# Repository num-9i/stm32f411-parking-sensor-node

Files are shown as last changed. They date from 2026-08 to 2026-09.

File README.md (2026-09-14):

# STM32F411RE Parking Sensor Node

STM32F411RE 기반으로 초음파 거리 측정, 주차 상태 판정, RGB LED 표시, Modbus RTU/RS485 통신을 구현한 주차 센서 노드 프로젝트입니다.

HC-SR04의 Echo pulse를 Timer Input Capture로 비동기 측정하고, 측정 결과에 hysteresis와 entry/exit delay를 적용해 `FREE / OCCUPIED / ERROR` 상태를 판정합니다.

센서 상태와 설정값은 Modbus Holding Register에 매핑했으며, `0x03 Read Holding Registers`와 `0x06 Write Single Register`를 통해 외부 Modbus Master에서 조회 및 변경할 수 있도록 구현했습니다.

현재 브레드보드 환경에서 펌웨어와 RS485 통신 검증을 완료했으며, NUCLEO-F411RE용 Carrier PCB도 Gerber/Drill 파일 생성 단계까지 완료했습니다. 실제 PCB 제작과 Bring-up은 다음 단계로 진행할 예정입니다.

## Project Status

- [x] Pin Map 정의
- [x] HC-SR04 거리 측정
- [x] TIM2 Input Capture / Interrupt 처리
- [x] 거리 측정 Timeout / Error Counter
- [x] FREE / OCCUPIED / ERROR 상태 판정
- [x] Hysteresis / Entry Delay / Exit Delay
- [x] RGB LED 상태 표시
- [x] Modbus RTU Function `0x03`
- [x] Modbus RTU Function `0x06`
- [x] Runtime Configuration
- [x] Modbus Exception Response
- [x] RS485 실통신 검증
- [x] Carrier PCB Schematic
- [x] Carrier PCB Layout / Routing
- [x] Carrier PCB ERC / DRC Verification
- [x] Gerber / Drill File Generation & Inspection
- [x] MAX3485용 PB5 DE/RE 제어 펌웨어 반영
- [ ] UART CLI
- [ ] PCB Fabrication
- [ ] PCB Bring-up / Hardware Verification

## System Overview

전체 데이터 흐름은 다음과 같습니다.

```text
HC-SR04
   │
   │ Echo Pulse
   ↓
TIM2 Input Capture
   │
   ↓
Distance Measurement
   │
   ↓
Parking State Logic
FREE / OCCUPIED / ERROR
   │
   ├──────────────→ RGB LED
   │
   ↓
Modbus Register Layer
   │
   ↓
Modbus RTU
   │
   ↓
USART1 / RS485
   │
   ↓
External Modbus Master
```

HC-SR04의 Echo pulse는 `TIM2_CH1 Input Capture`로 측정합니다.

측정된 거리 값은 주차 상태 판정 로직으로 전달되며, hysteresis와 entry/exit delay를 적용해 순간적인 거리 변화로 상태가 불필요하게 전환되는 것을 줄였습니다.

판정 결과와 센서 상태, 오류 카운터, 설정값은 Modbus Holding Register에 매핑해 외부 Master에서 확인할 수 있도록 구성했습니다.

## Hardware

### MCU / Development Board

- MCU: STM32F411RET6
- Board: NUCLEO-F411RE
- System Clock: 84 MHz

### Sensor / Indicator

- Distance Sensor: HC-SR04
- Status Indicator: Common Cathode RGB LED
- HC-SR04 Echo Interface: 1 kΩ / 2 kΩ Voltage Divider

### Communication

- Modbus UART: USART1
- Debug UART: USART2 / ST-LINK VCP
- Protocol: Modbus RTU
- Prototype RS485: Auto-direction TTL-to-RS485 Module
- Carrier PCB RS485: MAX3485
- PC Interface: USB-to-RS485 Adapter

상세 핀 구성은 아래 문서를 참고합니다.

- [Pin Map](docs/pin_map.md)

## HC-SR04 Distance Measurement

HC-SR04의 Trigger 신호를 출력한 뒤 Echo pulse의 High 구간을 측정해 거리를 계산합니다.

Echo 입력은 `PA0 / TIM2_CH1`에 연결하고, Timer를 1 MHz로 설정해 1 us 단위로 pulse width를 측정합니다.

```text
IDLE
  ↓
Trigger Pulse
  ↓
WAIT_RISING
  ↓
Rising Edge Capture
  ↓
WAIT_FALLING
  ↓
Falling Edge Capture
  ↓
Pulse Width Calculation
  ↓
DATA_READY
```

거리 계산에는 다음 관계를 사용합니다.

```text
Distance_mm = PulseWidth_us × 343 / 2000
```

센서 측정 범위는 약 `20 ~ 4000 mm`로 제한하며, 범위를 벗어난 pulse는 Invalid Pulse로 처리합니다.

정상적인 Echo 신호가 들어오지 않을 경우 무한 대기하지 않도록 Timeout을 적용했습니다.

구분하는 오류 항목은 다음과 같습니다.

- Rising Edge Timeout
- Falling Edge Timeout
- Invalid Pulse

각 오류는 별도의 Counter로 기록해 Modbus를 통해 확인할 수 있습니다.

## Parking State Logic

주차 상태는 다음 세 가지로 구분합니다.

| Value | State | Description |
|---:|---|---|
| `0` | FREE | 주차 공간이 비어 있는 상태 |
| `1` | OCCUPIED | 차량이 감지된 상태 |
| `2` | ERROR | 거리 측정이 일정 시간 이상 유효하지 않은 상태 |

기본 설정값은 다음과 같습니다.

```text
Occupied Threshold = 500 mm
Hysteresis         = 50 mm
Entry Delay        = 500 ms
Exit Delay         = 1000 ms
```

FREE 상태에서 거리가 `Occupied Threshold` 이하로 Entry Delay 동안 유지되면 OCCUPIED로 전환됩니다.

OCCUPIED 상태에서는 다음 기준을 사용합니다.

```text
Free Threshold =
    Occupied Threshold + Hysteresis
```

기본값 기준으로:

```text
Occupied Threshold = 500 mm
Free Threshold     = 550 mm
```

이므로 `500 mm < distance <= 550 mm` 구간에서는 현재 상태를 유지합니다.

따라서 임계값 부근에서 측정값이 흔들려도 상태가 즉시 반복 전환되지 않습니다.

거리 측정이 일정 시간 이상 유효하지 않을 경우 ERROR 상태로 전환합니다.

## RGB LED

주차 상태는 RGB LED로 표시합니다.

| Parking State | LED |
|---|---|
| FREE | Green |
| OCCUPIED | Red |
| ERROR | Blue |

GPIO 구성:

```text
PB12 → Red
PB13 → Green
PB14 → Blue
```

RGB LED는 Active High 방식으로 제어합니다.

## Modbus RTU / RS485

외부 장치에서 센서 상태와 설정값을 확인하거나 변경할 수 있도록 Modbus RTU Slave를 구현했습니다.

지원하는 Function Code는 다음과 같습니다.

- `0x03` Read Holding Registers
- `0x06` Write Single Register

통신 설정:

- Slave ID: `1`
- Baud Rate: `115200`
- Format: `8-N-1`
- Interface: USART1 / RS485

### Prototype RS485

브레드보드 프로토타입에서는 자동 방향 제어 TTL-to-RS485 모듈을 사용했습니다.

```text
PA9  / USART1_TX  → RS485 Module RXD
PA10 / USART1_RX  ← RS485 Module TXD
```

모듈 내부에서 송수신 방향을 자동으로 전환하므로 별도의 DE/RE GPIO가 필요하지 않습니다.

### Carrier PCB RS485

Carrier PCB에서는 `MAX3485`를 사용합니다.

```text
PA9  / USART1_TX  → MAX3485 DI
PA10 / USART1_RX  ← MAX3485 RO
PB5               → MAX3485 DE + /RE
```

`DE`와 `/RE`는 하나의 GPIO로 묶어 다음과 같이 제어합니다.

```text
PB5 LOW  → Receive Mode
PB5 HIGH → Transmit Mode
```

Modbus 응답을 송신하기 직전에 PB5를 HIGH로 설정하고, `HAL_UART_Transmit()` 완료 후 LOW로 복귀시켜 다시 Receive Mode로 전환합니다.

PCB에는 PB5에 10 kΩ Pull-down 저항을 적용해 MCU Reset 중에도 기본적으로 Driver가 비활성화되고 Receiver가 활성화되도록 구성했습니다.

브레드보드의 자동 방향 제어 모듈에는 PB5가 연결되지 않으므로, 해당 제어 코드를 추가한 뒤에도 기존 Prototype의 FC03 / FC06 통신이 정상적으로 동작하는 것을 확인했습니다.

## Holding Register Map

| Address | Name | Access |
|---|---|---|
| `0x0000` | Distance_mm | R |
| `0x0001` | Parking_State | R |
| `0x0002` | Status_Flags | R |
| `0x0003` | Total_Error_Count | R |
| `0x0004` | Rising_Timeout_Count | R |
| `0x0005` | Falling_Timeout_Count | R |
| `0x0006` | Invalid_Pulse_Count | R |
| `0x0007` | Occupied_Threshold_mm | R/W |
| `0x0008` | Hysteresis_mm | R/W |
| `0x0009` | Entry_Delay_ms | R/W |
| `0x000A` | Exit_Delay_ms | R/W |

상세한 Register Map과 설정값 검증 규칙은 아래 문서에 정리했습니다.

- [Modbus Register Map](docs/register_map.md)

## Runtime Configuration

`0x0007`~`0x000A` Register는 Modbus `0x06 Write Single Register`를 통해 실행 중에 변경할 수 있습니다.

예를 들어 Occupied Threshold의 기본값은 500 mm입니다.

```text
Register: 0x0007

500 mm
0x01F4

      ↓ FC06

300 mm
0x012C
```

설정값을 변경하면 주차 상태 판정 로직에서 즉시 새로운 값을 사용합니다.

현재 설정값은 RAM에만 저장되므로 Reset 또는 전원 재인가 후에는 기본값으로 돌아갑니다.

## Modbus Exception Handling

지원하지 않는 요청이나 잘못된 설정값에는 Modbus Exception Response를 반환합니다.

| Exception | Description |
|---|---|
| `0x01` | Illegal Function |
| `0x02` | Illegal Data Address |
| `0x03` | Illegal Data Value |

예를 들어 읽기 전용 Register인 `0x0000`에 `0x06` Write 요청을 보내면 `0x02 Illegal Data Address`를 반환합니다.

허용 범위를 벗어난 Occupied Threshold를 설정하면 `0x03 Illegal Data Value`를 반환합니다.

## Verification

### FC03 — Holding Register Read

Modbus Client에서 `0x0000`~`0x000A` Register를 한 번에 읽어 거리, 주차 상태, 오류 카운터, 설정값을 확인했습니다.

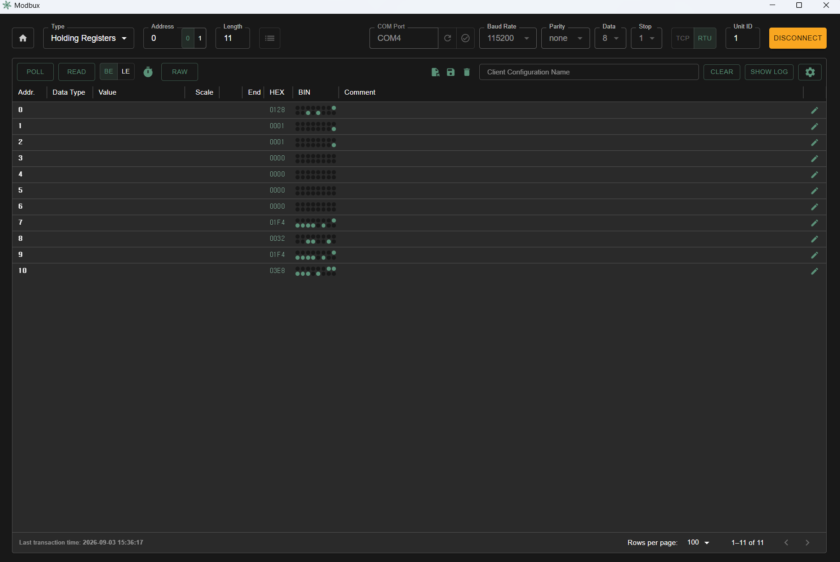
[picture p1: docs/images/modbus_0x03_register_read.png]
Modbus FC03 Register Read


### Request / Response Frame

UART Debug 출력을 통해 실제 Modbus RTU Request와 Response 데이터를 확인했습니다.

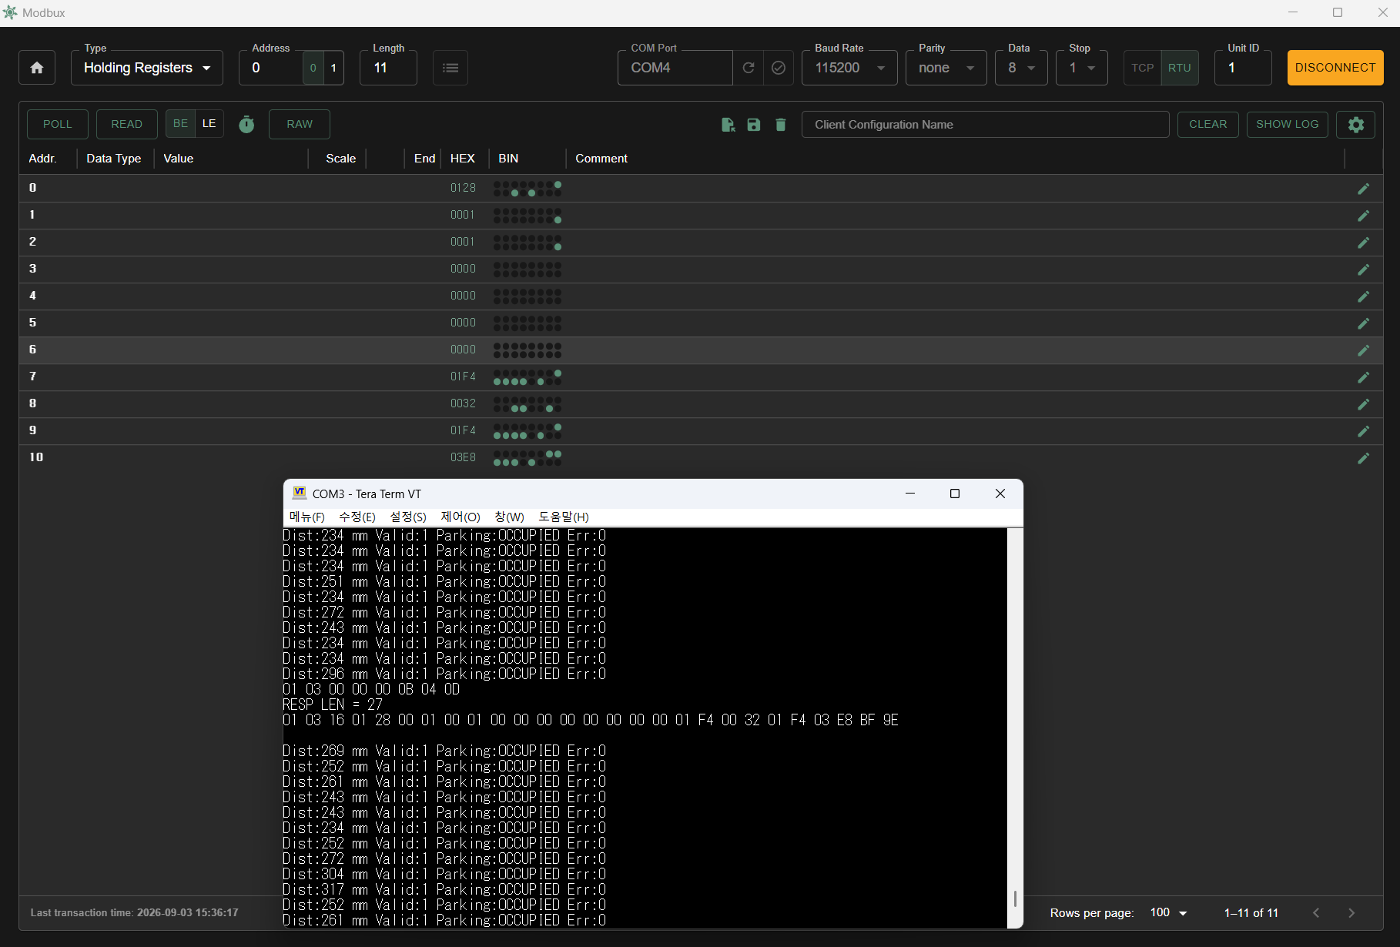
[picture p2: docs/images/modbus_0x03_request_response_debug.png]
Modbus Request Response


### FC06 — Runtime Threshold Change

Occupied Threshold를 `500 mm`에서 `300 mm`로 변경한 뒤 Write 결과와 실제 주차 상태 전환 기준 변경을 확인했습니다.

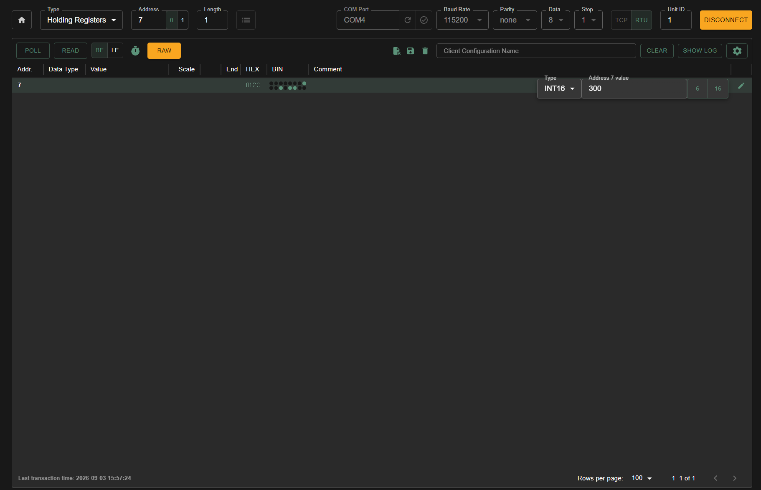
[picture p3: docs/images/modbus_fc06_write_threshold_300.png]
Modbus FC06 Threshold Write


### Exception — Illegal Data Address

읽기 전용 Register에 Write 요청을 전송해 `0x02 Illegal Data Address` 응답을 확인했습니다.

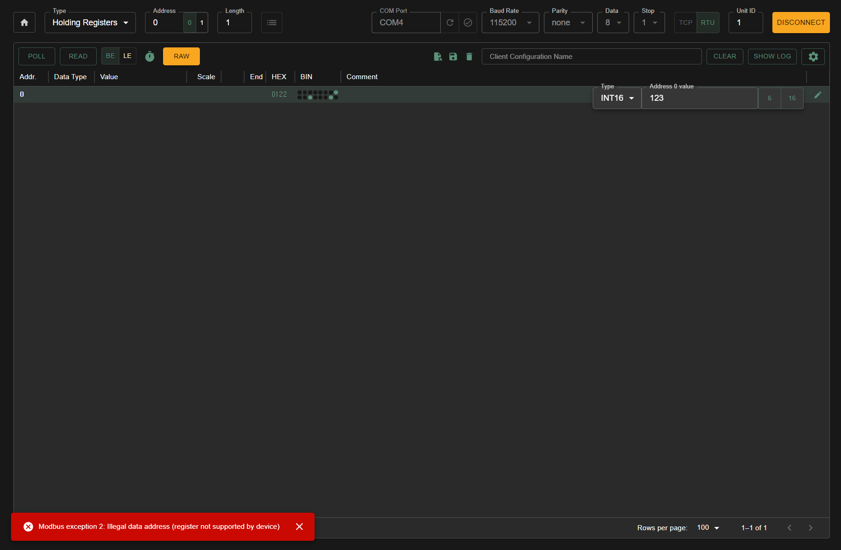
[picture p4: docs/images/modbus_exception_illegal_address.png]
Illegal Data Address


### Exception — Illegal Data Value

허용 범위를 벗어난 설정값을 전송해 `0x03 Illegal Data Value` 응답을 확인했습니다.

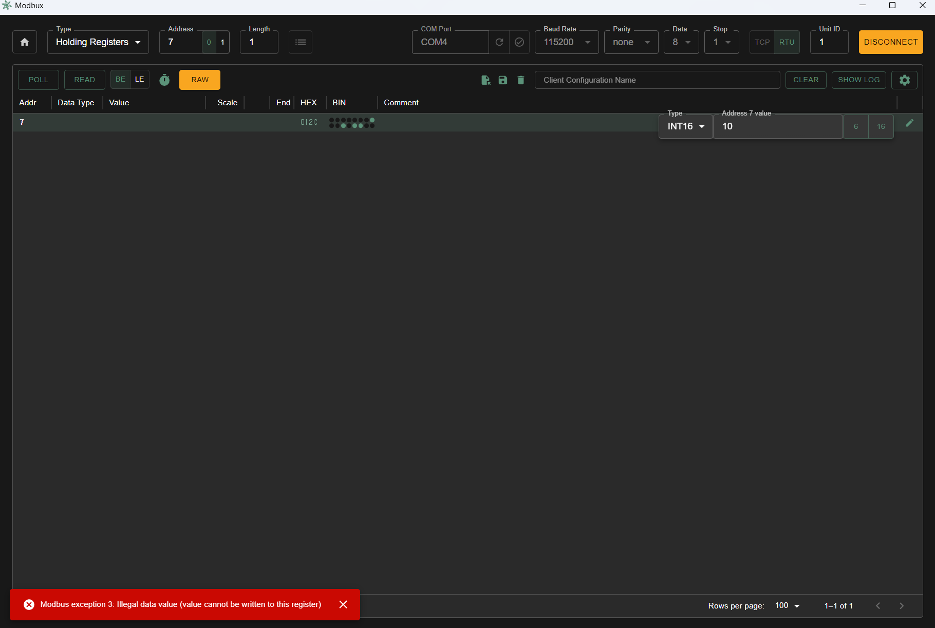
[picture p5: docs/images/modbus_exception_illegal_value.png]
Illegal Data Value


## Carrier PCB Design

브레드보드 프로토타입을 실제 조립 가능한 구조로 확장하기 위해 NUCLEO-F411RE용 Carrier PCB를 KiCad로 설계했습니다.

Carrier PCB에는 다음 회로를 포함합니다.

- NUCLEO-F411RE Interface
- HC-SR04 Connector
- HC-SR04 Echo Voltage Divider
- RGB Status LED
- MAX3485 RS485 Transceiver
- MAX3485 100 nF Decoupling Capacitor
- PB5 DE/RE Pull-down
- RS485 A / B / GND Terminal Block
- Selectable 120 Ω RS485 Termination

RS485 종단저항은 Solder Jumper를 사용해 필요할 때만 활성화할 수 있도록 구성했습니다.

```text
RS485_A ── 120 Ω ── JP1 ── RS485_B
```

### PCB 3D Overview

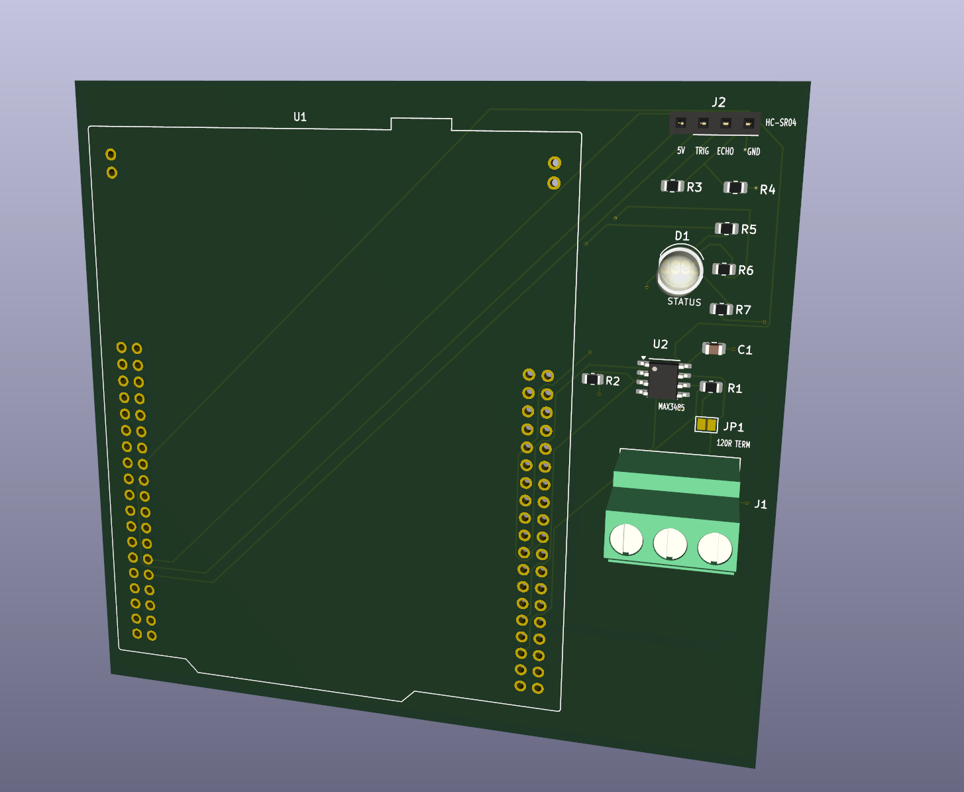
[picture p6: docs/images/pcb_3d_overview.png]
Carrier PCB 3D Overview


### RS485 / Sensor Section

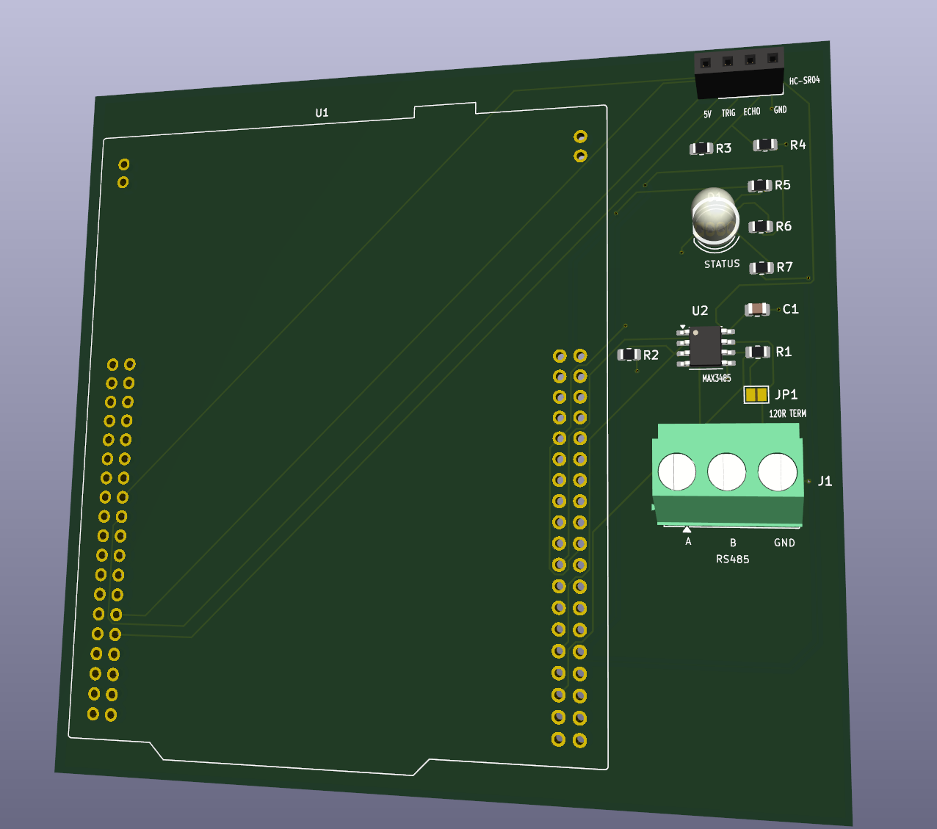
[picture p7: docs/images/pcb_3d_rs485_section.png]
Carrier PCB RS485 Section


PCB는 2-Layer로 구성했으며, B.Cu에 GND Copper Zone을 적용했습니다. ERC와 DRC는 모두 Error / Warning 0건을 확인했습니다.

구매한 Common Cathode RGB LED의 `B-G-K-R` Pin Order에 맞춰 전용 Footprint를 추가하고, D1의 Drill Diameter를 `0.8 mm`로 조정해 Annular Ring 규칙을 만족시켰습니다.

이후 Gerber와 PTH / NPTH Drill File을 생성하고 KiCad Gerber Viewer에서 Edge.Cuts, Copper, Solder Mask, Silkscreen, Drill Layer를 확인했습니다.

KiCad 프로젝트와 제조용 출력 파일은 다음 경로에 포함되어 있습니다.

```text
hardware/
└─ parking_sensor_node/
   ├─ parking_sensor_node.kicad_pro
   ├─ parking_sensor_node.kicad_sch
   ├─ parking_sensor_node.kicad_pcb
   ├─ fp-lib-table
   ├─ footprints/
   │  └─ ParkingSensor.pretty/
   │     └─ LED_D5.0mm-4_RGB_BGKR.kicad_mod
   └─ gerber/
      ├─ *.gbr
      ├─ *-PTH.drl
      └─ *-NPTH.drl
```

## Software Structure

주요 모듈은 다음과 같이 분리했습니다.

```text
Core/
├─ Inc/
│  ├─ hcsr04.h
│  ├─ parking_logic.h
│  ├─ rgb_led.h
│  ├─ app_config.h
│  ├─ modbus_crc.h
│  ├─ modbus_registers.h
│  └─ modbus_rtu.h
│
└─ Src/
   ├─ hcsr04.c
   ├─ parking_logic.c
   ├─ rgb_led.c
   ├─ app_config.c
   ├─ modbus_crc.c
   ├─ modbus_registers.c
   └─ modbus_rtu.c
```

각 모듈의 역할을 분리해 센서 측정, 상태 판정, 설정값 관리, Register Mapping, Modbus Frame 처리가 서로 직접 의존하지 않도록 구성했습니다.

## Current Limitations

현재 구현은 프로젝트 범위에 맞춰 다음과 같이 제한되어 있습니다.

- Modbus Function `0x03`, `0x06`만 지원
- UART RX는 현재 지원하는 8-byte Request Frame을 기준으로 처리
- Generic Modbus RTU Frame Gap Detection 미구현
- 통신 중 Partial Frame이 남은 상태에서 Master가 재연결될 경우 Frame 정렬이 깨질 수 있음
- 설정값은 RAM에만 저장
- UART CLI 미구현
- Carrier PCB 실물 제작 및 Bring-up 미완료
- MAX3485 기반 수동 DE/RE 제어는 펌웨어에 반영했으나 실제 Carrier PCB에서의 Hardware Verification은 아직 진행 전

현재 브레드보드 환경에서는 센서 측정, 상태 판정, RGB 표시, Modbus FC03 / FC06, Exception Response 및 RS485 실통신까지 검증했습니다.

## Next Step

다음 단계에서는 구매한 부품이 도착한 뒤 실제 부품과 Footprint를 대조하고 Carrier PCB 제작 및 Bring-up을 진행합니다.

제작 전 실물 기준으로 다음 항목을 확인할 예정입니다.

- MAX3485 SOIC-8 Package
- 3-pin RS485 Terminal Block의 5.08 mm Pitch / 방향
- RGB LED의 실제 Pin Order / Lead Pitch
- HC-SR04 Connector 및 기구 간섭

PCB 제작 후에는 다음 항목을 검증할 예정입니다.

```text
Power / Ground
    ↓
HC-SR04 Measurement
    ↓
RGB State Output
    ↓
MAX3485 DE/RE Control
    ↓
Modbus FC03 / FC06
    ↓
Exception Response
    ↓
Long-term Communication Test
```

PCB 제작 후에는 브레드보드에서 검증한 기능을 Carrier PCB에서도 동일한 순서로 Bring-up할 예정입니다.

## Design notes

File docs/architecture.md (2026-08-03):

# System Architecture

## System Flow

```text
                         +------------------+
                         |     HC-SR04      |
                         +--------+---------+
                                  |
                                  v
                         +------------------+
                         |  hcsr04 driver   |
                         +--------+---------+
                                  |
                                  v
                         +------------------+
                         |  parking logic   |
                         +--------+---------+
                                  |
                                  v
                         +------------------+
                         |   parking data   |
                         +----+--------+----+
                              |        |
                 +------------+        +-------------+
                 |                                   |
                 v                                   v
        +------------------+               +------------------+
        |  RGB Status LED  |               |     UART CLI     |
        | FREE/OCC/ERROR   |               | USART2 / VCP     |
        +------------------+               +------------------+

                                  |
                                  v
                         +------------------+
                         |   Modbus RTU     |
                         | USART1 / RS485   |
                         +------------------+
```

## Module Responsibilities

### `hcsr04`

- Trigger pulse generation
- Rising and falling edge capture
- Pulse width calculation
- Distance conversion
- Timeout and error detection

### `parking_logic`

- `FREE / OCCUPIED / ERROR` determination
- Entry and exit delay
- Hysteresis
- Consecutive failure handling

### `parking_data`

- Latest distance
- Parking state
- Valid flags
- Status flags
- Error counters
- Shared data for CLI and Modbus

### `led_status`

- RGB LED output control
- Parking state indication
- Error state indication

### `uart_cmd`

- Runtime diagnostics
- Configuration commands
- Internal state inspection

### `modbus_rtu`

- CRC16 calculation
- Function `0x03`
- Function `0x06`
- Register access validation
- Exception responses

### `app_config`

- Installation height
- Detection threshold
- Entry and exit delay
- Configuration range validation

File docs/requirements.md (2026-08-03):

# Project Requirements

## Goal

STM32F411RE 기반으로 초음파 거리 측정, 주차 상태 판정,
RGB LED 표시, UART CLI 및 Modbus RTU/RS485 통신이 가능한
주차 상태 센서 노드를 구현한다.

## Parking States

- FREE
- OCCUPIED
- ERROR

## Required Features

- HC-SR04 Trigger pulse generation
- TIM Input Capture based Echo measurement
- Rising edge timeout
- Falling edge timeout
- Invalid pulse detection
- Distance measurement in millimeters
- Entry and exit delay
- Hysteresis
- RGB LED status indication
- UART CLI
- Modbus RTU Function 0x03
- Modbus RTU Function 0x06
- Cause-specific error counters
- KiCad Carrier PCB
- Board Bring-up and waveform verification

## Out of Scope

- Database
- Web or mobile application
- Multi-floor parking map
- Modbus TCP display system
- ESP32 wireless communication

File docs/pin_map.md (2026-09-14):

# Pin Map

## MCU / Board

- MCU: STM32F411RET6
- Board: NUCLEO-F411RE
- System Clock: 84 MHz

## Peripheral Pin Assignment

| 기능 | Peripheral | Pin | 방향 | 설명 |
|---|---|---:|---|---|
| HC-SR04 Echo | TIM2_CH1 | PA0 | Input | Echo pulse Input Capture, Timer 분해능: 1 us |
| HC-SR04 Trigger | GPIO | PA1 | Output | 초음파 측정 시작용 Trigger pulse 출력 |
| Debug / CLI TX | USART2_TX | PA2 | Output | ST-LINK Virtual COM Port |
| Debug / CLI RX | USART2_RX | PA3 | Input | ST-LINK Virtual COM Port, 향후 CLI 입력용 |
| Onboard LED | GPIO | PA5 | Output | NUCLEO LD2, Bring-up / Debug 용도 |
| Modbus TX | USART1_TX | PA9 | Output | RS485 Transceiver DI / Prototype Module RXD |
| Modbus RX | USART1_RX | PA10 | Input | RS485 Transceiver RO / Prototype Module TXD |
| RS485 DE/RE | GPIO | PB5 | Output | 최종 Carrier PCB MAX3485 방향 제어, LOW=RX / HIGH=TX |
| RGB Red | GPIO | PB12 | Output | OCCUPIED 상태 표시 |
| RGB Green | GPIO | PB13 | Output | FREE 상태 표시 |
| RGB Blue | GPIO | PB14 | Output | ERROR 상태 표시 |

## TIM2 Configuration

HC-SR04의 Echo pulse 폭을 측정하기 위해 `TIM2_CH1 Input Capture`를 사용합니다.

- Channel: CH1 Input Capture
- Timer Input Clock: 84 MHz
- Prescaler: 83
- Counter Frequency: 1 MHz
- Counter Resolution: 1 us
- Counter Period: 0xFFFFFFFF
- Initial Capture Polarity: Rising Edge
- Input Capture Prescaler: No Division
- Input Filter: 0
- TIM2 Global Interrupt: Enabled

Echo 신호의 Rising Edge에서 측정 시작 시점을 저장한 뒤, Capture Polarity를 Falling Edge로 변경해 종료 시점을 측정합니다.

```text
Rising Edge
    ↓
시작 시각 Capture
    ↓
Falling Edge
    ↓
종료 시각 Capture
    ↓
Echo Pulse Width 계산
    ↓
Distance 계산
```

측정한 Echo pulse width는 HC-SR04 드라이버에서 거리 값으로 변환합니다.

## UART Configuration

### USART2 — Debug / Future CLI

- Pins: PA2 / PA3
- Baud Rate: 115200
- Format: 8-N-1
- Hardware Flow Control: None
- Connection: ST-LINK Virtual COM Port

현재 `USART2`는 센서 측정값과 주차 상태 확인을 위한 Debug 출력에 사용합니다.

향후 UART CLI를 추가할 경우 동일한 USART2 / ST-LINK VCP를 사용할 수 있도록 핀을 할당했습니다.

Modbus 통신과 Debug UART를 서로 분리해, 외부 Modbus Master와 통신하는 동안에도 ST-LINK VCP를 통해 내부 상태를 확인할 수 있도록 구성했습니다.

### USART1 — Modbus RTU / RS485

- Pins: PA9 / PA10
- Baud Rate: 115200
- Format: 8-N-1
- Hardware Flow Control: None
- USART1 Global Interrupt: Enabled

현재 브레드보드 프로토타입의 RS485 연결 구성은 다음과 같습니다.

```text
NUCLEO PA9 (USART1_TX)
        ↓
Auto-direction RS485 Module RXD

NUCLEO PA10 (USART1_RX)
        ↑
Auto-direction RS485 Module TXD
```

프로토타입에서 사용하는 RS485 모듈은 송수신 방향을 자동으로 전환합니다.

최종 Carrier PCB에서는 `MAX3485`를 사용하며, `/RE`와 `DE`를 하나의 제어 신호로 묶어 `PB5`에서 직접 제어합니다.

```text
PB5 LOW
    ↓
DE  = 0
/RE = 0
    ↓
Receive Mode

PB5 HIGH
    ↓
DE  = 1
/RE = 1
    ↓
Transmit Mode
```

Modbus 응답 송신 직전에 `PB5`를 HIGH로 설정하고, `HAL_UART_Transmit()` 완료 후 LOW로 복귀시켜 다시 수신 상태로 전환합니다.

현재 브레드보드 프로토타입의 자동 방향 제어 RS485 모듈에는 `PB5`가 물리적으로 연결되지 않으므로, 이 GPIO 제어는 프로토타입 통신에는 영향을 주지 않습니다.

## HC-SR04 Electrical Interface

HC-SR04는 5 V 전원으로 동작합니다.

HC-SR04의 Echo 출력은 약 5 V이므로 STM32 입력 핀에 직접 연결하지 않고 저항 분압 회로를 사용했습니다.

현재 프로토타입과 Carrier PCB의 분압 구성은 다음과 같습니다.

```text
HC-SR04 ECHO
    |
   1 kΩ
    |
    +------ PA0 / TIM2_CH1
    |
   2 kΩ
    |
   GND
```

이 구성으로 Echo 신호 전압을 약 3.3 V 수준으로 낮춘 뒤 STM32에 입력합니다.

## RGB LED

주차 상태를 표시하기 위해 RGB LED를 사용합니다.

RGB LED는 Active High 방식으로 제어합니다.

| Parking State | LED |
|---|---|
| FREE | Green |
| OCCUPIED | Red |
| ERROR | Blue |

사용 핀은 다음과 같습니다.

```text
PB12 → Red
PB13 → Green
PB14 → Blue
```

주차 상태 판정 결과에 따라 해당 색상의 LED를 출력합니다.

## RS485 Prototype Wiring

RS485 실통신 검증에는 자동 방향 제어 TTL-to-RS485 모듈과 USB-to-RS485 어댑터를 사용했습니다.

```text
STM32F411RE                  Auto-direction RS485 Module

PA9  / USART1_TX  --------> RXD
PA10 / USART1_RX  <-------- TXD
GND                 ------- GND
5V                  ------- VCC

                            D+ / A ------ USB-RS485 A
                            D- / B ------ USB-RS485 B
                            GND    ------ USB-RS485 GND
```

RS485 모듈은 NUCLEO 보드의 5 V 전원을 사용합니다.

USB-to-RS485 어댑터의 `+5 V` 출력은 NUCLEO 보드에 연결하지 않고, `A`, `B`, `GND`만 연결했습니다.

## 현재 프로토타입 구조

현재 프로토타입의 주요 신호 흐름은 다음과 같습니다.

```text
HC-SR04
   │
   ├─ Trigger → PA1
   │
   └─ Echo → Voltage Divider → PA0 / TIM2_CH1
                                  │
                                  ↓
                         Distance Measurement
                                  │
                                  ↓
                         Parking State Logic
                         FREE / OCCUPIED / ERROR
                                  │
                    ┌─────────────┴─────────────┐
                    ↓                           ↓
                 RGB LED                   Modbus Registers
                                                │
                                                ↓
                                             USART1
                                                │
                                                ↓
                                             RS485
```

`USART2`는 위 제어 흐름과 별도로 Debug 출력에 사용합니다.

## PCB Design Note

브레드보드 프로토타입과 최종 Carrier PCB의 RS485 방향 제어 방식은 다릅니다.

| 구분 | RS485 Interface | Direction Control |
|---|---|---|
| Prototype | Auto-direction TTL-to-RS485 Module | 모듈 내부 자동 전환 |
| Carrier PCB | MAX3485 | PB5 GPIO로 `/RE` + `DE` 직접 제어 |

최종 Carrier PCB에서는 `PB5`를 `RS485_DE_RE` 신호로 사용합니다.

PCB에는 `PB5` 신호에 10 kΩ Pull-down 저항을 적용해 MCU Reset 중에도 RS485 Driver가 비활성화되고 Receiver가 활성화되도록 구성했습니다.

Carrier PCB의 RS485 신호 연결은 다음과 같습니다.

```text
PA9 / USART1_TX  → MAX3485 DI
PA10 / USART1_RX ← MAX3485 RO
PB5              → MAX3485 DE + /RE

MAX3485 A        → RS485 A
MAX3485 B        → RS485 B
```

A-B 사이의 120 Ω 종단저항은 Solder Jumper를 통해 선택적으로 연결할 수 있도록 구성했습니다.

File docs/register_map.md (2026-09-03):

# Modbus Register Map

The parking sensor node operates as a Modbus RTU slave.

- Slave ID: `1`
- Baud rate: `115200`
- Data format: `8N1`
- Supported functions:
  - `0x03` Read Holding Registers
  - `0x06` Write Single Register

## Holding Registers

| Address | Name | Access | Default | Description |
|---|---|---|---:|---|
| `0x0000` | Distance_mm | R | - | Latest measured distance in millimeters |
| `0x0001` | Parking_State | R | - | Current parking state |
| `0x0002` | Status_Flags | R | - | Sensor and parking status bitfield |
| `0x0003` | Total_Error_Count | R | 0 | Sum of HC-SR04 error counters |
| `0x0004` | Rising_Timeout_Count | R | 0 | Rising-edge timeout count |
| `0x0005` | Falling_Timeout_Count | R | 0 | Falling-edge timeout count |
| `0x0006` | Invalid_Pulse_Count | R | 0 | Invalid echo pulse count |
| `0x0007` | Occupied_Threshold_mm | R/W | 500 | Distance threshold for OCCUPIED state |
| `0x0008` | Hysteresis_mm | R/W | 50 | Hysteresis added to occupied threshold |
| `0x0009` | Entry_Delay_ms | R/W | 500 | Required time below occupied threshold before entering OCCUPIED |
| `0x000A` | Exit_Delay_ms | R/W | 1000 | Required time above free threshold before entering FREE |

## Parking State

| Value | State |
|---:|---|
| `0` | FREE |
| `1` | OCCUPIED |
| `2` | ERROR |

## Status Flags

| Bit | Mask | Meaning |
|---:|---:|---|
| 0 | `0x0001` | Distance valid |
| 1 | `0x0002` | Sensor error |
| 2 | `0x0004` | Parking state is ERROR |

Example:

```text
Status_Flags = 0x0001
```

This means that the current distance measurement is valid and no sensor or parking error flag is active.

## Parking Threshold Logic

The FREE threshold is calculated at runtime as:

```text
Free_Threshold_mm =
    Occupied_Threshold_mm + Hysteresis_mm
```

With the default configuration:

```text
Occupied threshold = 500 mm
Hysteresis         = 50 mm
Free threshold     = 550 mm
Entry delay        = 500 ms
Exit delay         = 1000 ms
```

Therefore:

- `distance <= 500 mm` maintained for 500 ms → `OCCUPIED`
- `distance > 550 mm` maintained for 1000 ms → `FREE`
- `500 mm < distance <= 550 mm` → current parking state is retained

## Runtime Configuration

Registers `0x0007` through `0x000A` can be modified at runtime using Modbus function `0x06`.

Example:

```text
Register 0x0007

500 mm (0x01F4)
        ↓ FC06
300 mm (0x012C)
```

The updated value is applied immediately to the parking decision logic.

Configuration is currently stored in RAM only and returns to the default values after reset or power cycle.

## Validation

### Occupied Threshold

`Occupied_Threshold_mm` must be at least `20 mm`.

The configuration is rejected if:

```text
Occupied_Threshold_mm + Hysteresis_mm > 4000 mm
```

because the HC-SR04 measurement range used by the firmware is limited to 4000 mm.

### Hysteresis

The hysteresis value is rejected if:

```text
Occupied_Threshold_mm + Hysteresis_mm > 4000 mm
```

### Entry and Exit Delay

Entry and exit delays are stored as unsigned 16-bit millisecond values.

Valid range:

```text
0 to 65535 ms
```

A value of `0` effectively disables the corresponding transition delay.

## Error Counter Representation

The internal HC-SR04 error counters are stored as 32-bit values.

Because a Modbus holding register is 16 bits, values greater than `65535` are saturated to:

```text
0xFFFF
```

instead of wrapping around.

## Distance Validity

`Distance_mm` retains the latest stored distance value even when the current measurement becomes invalid.

Therefore, a Modbus client must check:

```text
Status_Flags bit 0
```

before treating `Distance_mm` as a valid current measurement.

## Modbus Exceptions

| Exception Code | Name | Usage |
|---:|---|---|
| `0x01` | Illegal Function | Unsupported Modbus function |
| `0x02` | Illegal Data Address | Invalid register address or write attempt to a read-only register |
| `0x03` | Illegal Data Value | Invalid quantity or rejected configuration value |

Examples verified over RS485:

```text
FC06 write to 0x0000
→ Exception 0x02

FC06 write 10 mm to 0x0007
→ Exception 0x03
```

## Byte Order

Modbus register values use big-endian byte order.

Example:

```text
500 decimal = 0x01F4

Register data:
01 F4
```

The Modbus CRC field is transmitted low byte first.

Example:

```text
CRC value = 0x0A84

Wire order:
84 0A
```

## Communication Flow

The current implementation uses USART1 for Modbus RTU communication.

```text
PC Modbus Client
    ↓
USB-RS485 Adapter
    ↓
RS485 Bus
    ↓
Auto-direction RS485 Module
    ↓
USART1
    ↓
Modbus RTU Parser
    ↓
Register Layer
    ↓
Parking Sensor Application
```

The RS485 module handles transmit/receive direction automatically, so no MCU-controlled DE/RE signal is required.

## Current Limitation

The UART receive path currently expects the supported `0x03` and `0x06` requests as fixed 8-byte Modbus RTU frames.

Generic variable-length Modbus RTU frame detection is not implemented.

This implementation is therefore intentionally scoped to the currently supported request formats rather than acting as a general-purpose Modbus RTU stack.

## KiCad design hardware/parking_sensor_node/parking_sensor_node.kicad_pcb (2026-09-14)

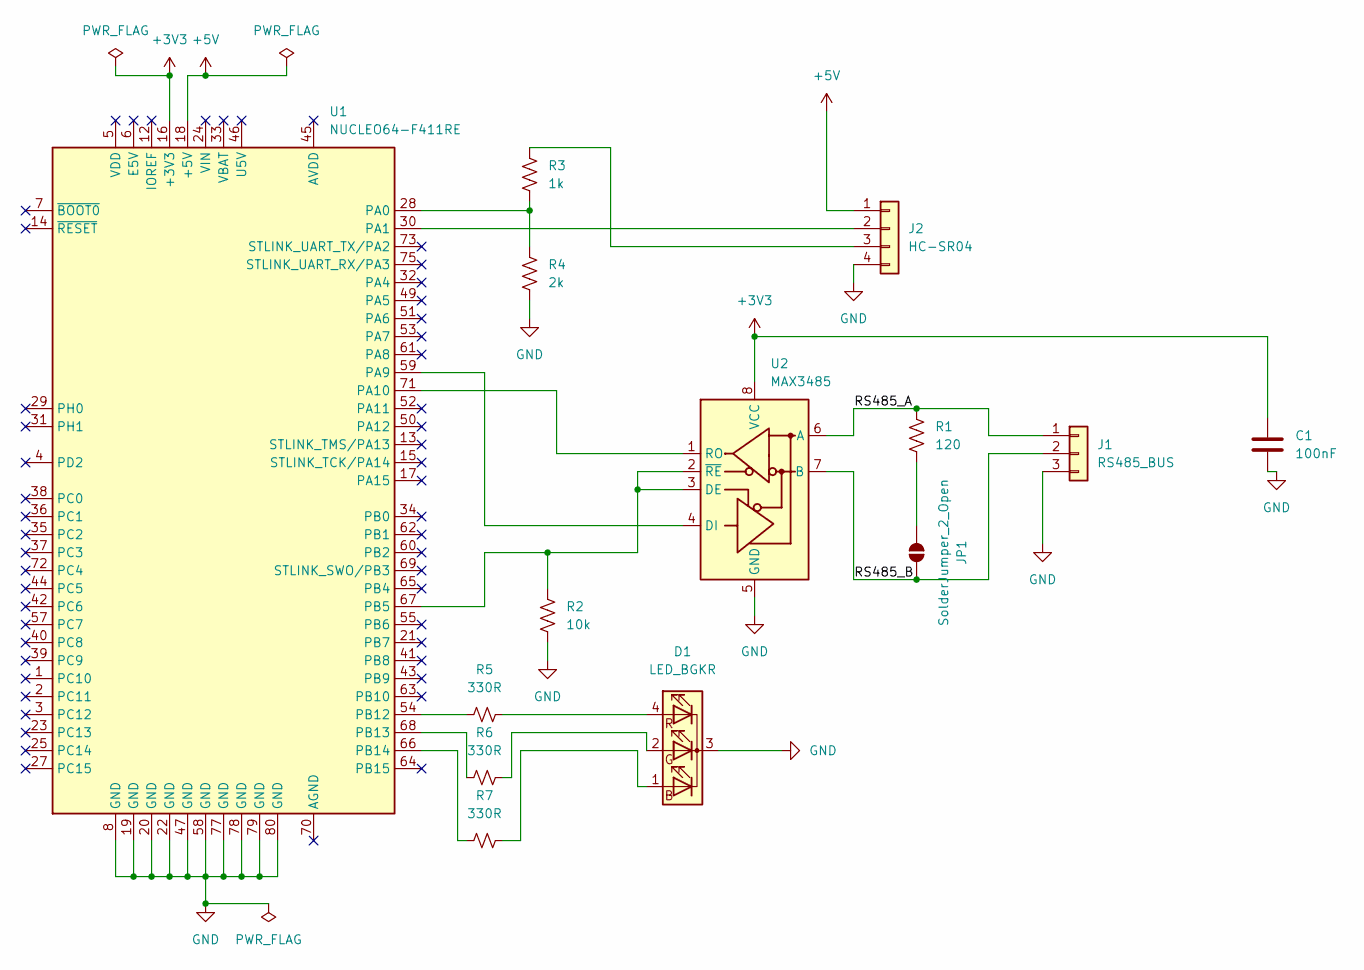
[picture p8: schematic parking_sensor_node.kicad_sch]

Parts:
C1: 100nF; C_0805_2012Metric
D1: LED_BGKR; LED_D5.0mm-4_RGB_BGKR
J1: RS485_BUS; TerminalBlock_Phoenix_MKDS-3-3-5.08_1x03_P5.08mm_Horizontal
J2: HC-SR04; PinSocket_1x04_P2.54mm_Vertical
JP1: SolderJumper_2_Open; SolderJumper-2_P1.3mm_Open_Pad1.0x1.5mm
R1: 120; R_0805_2012Metric
R2: 10k; R_0805_2012Metric
R3: 1k; R_0805_2012Metric
R4: 2k; R_0805_2012Metric
R5, R6, R7: 330R; R_0805_2012Metric
U1: NUCLEO64-F411RE; ST_Morpho_Connector_64_STLink
U2: MAX3485; SOIC-8_3.9x4.9mm_P1.27mm

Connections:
+3V3: C1.1, U1.16 (+3V3), U2.8 (VCC)
+5V: J2.1, U1.18 (+5V)
/RS485_A: J1.1, R1.1, U2.6 (A)
/RS485_B: J1.2, JP1.2 (B), U2.7 (B)
GND: C1.2, D1.3 (K), J1.3, J2.4, R2.2, R4.2, U1.8 (GND), U1.19 (GND), U1.20 (GND), U1.22 (GND), U1.47 (GND), U1.58 (GND), U1.77 (GND), U1.78 (GND), U1.79 (GND), U1.80 (GND), U2.5 (GND)
unnamed: D1.1 (BA), R7.2
unnamed: D1.2 (GA), R6.2
unnamed: D1.4 (RA), R5.2
unnamed: J2.2, U1.30 (PA1)
unnamed: J2.3, R3.1
unnamed: JP1.1 (A), R1.2
unnamed: R3.2, R4.1, U1.28 (PA0)
unnamed: U1.59 (PA9), U2.4 (DI)
unnamed: U1.71 (PA10), U2.1 (RO)
unnamed: R2.1, U1.67 (PB5), U2.2 (~RE), U2.3 (DE)
unnamed: R5.1, U1.54 (PB12)
unnamed: R6.1, U1.68 (PB13)
unnamed: R7.1, U1.66 (PB14)

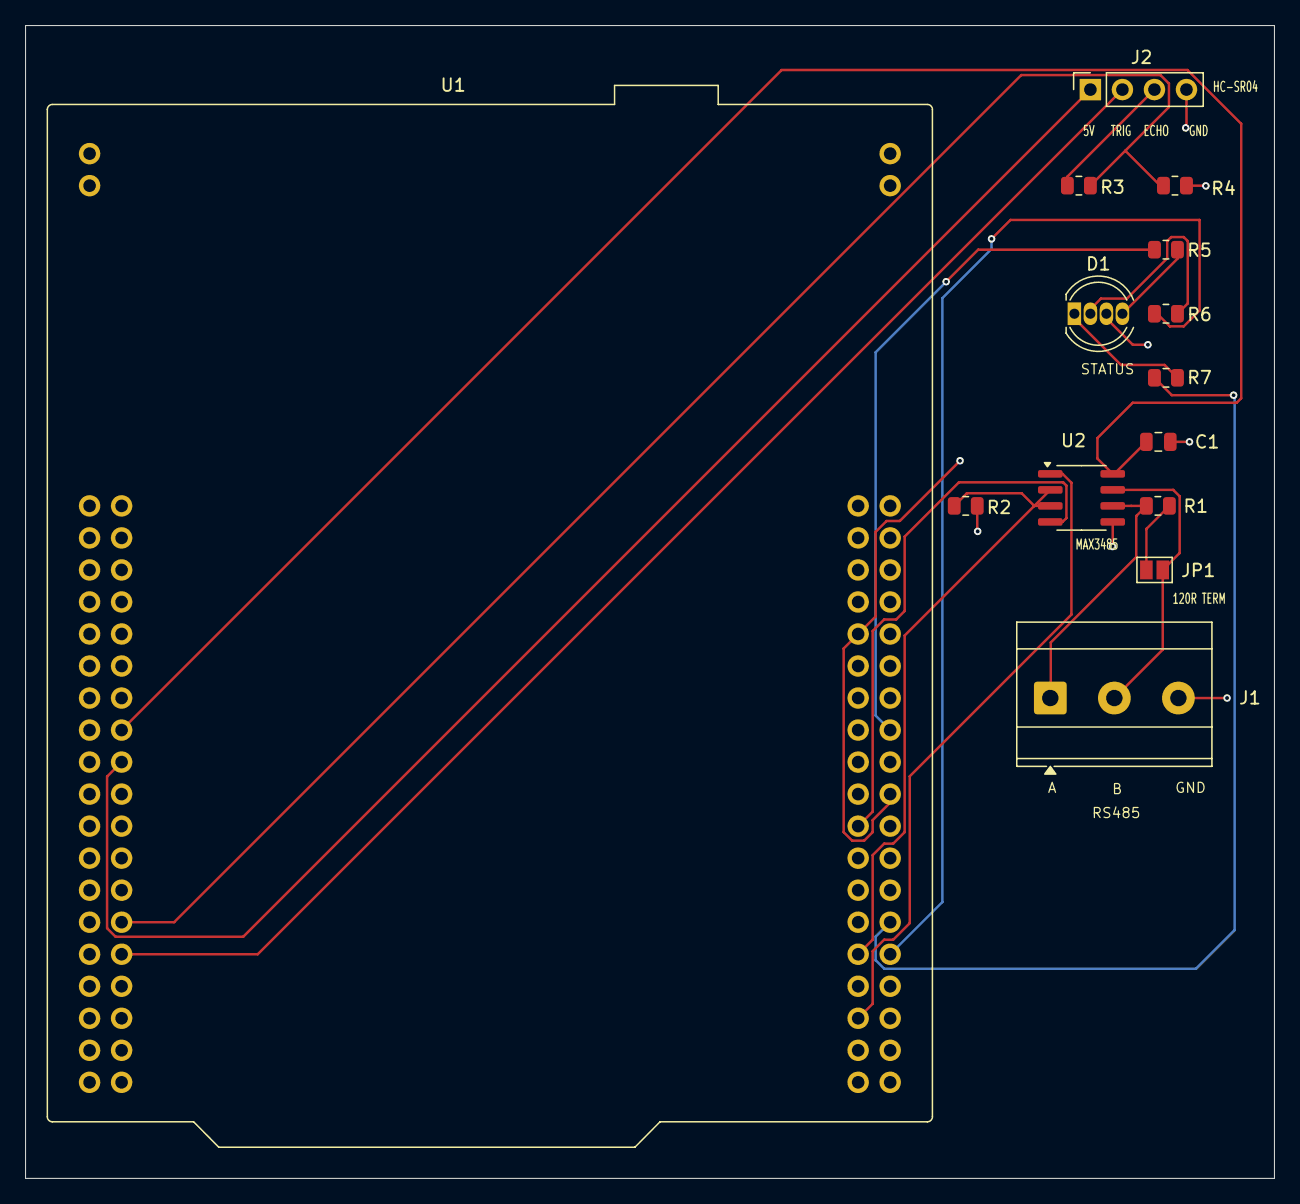
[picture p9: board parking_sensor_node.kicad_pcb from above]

Board: 2 copper layers, 99.1 x 91.4 mm, 14 parts (0 on the bottom side), 18 nets.

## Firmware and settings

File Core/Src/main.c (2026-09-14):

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
/* Includes ------------------------------------------------------------------*/
#include "main.h"

/* USER CODE BEGIN Includes */
#include "hcsr04.h"
#include "parking_logic.h"
#include "rgb_led.h"
#include "app_config.h"
#include "modbus_rtu.h"
#include <stdio.h>

/* USER CODE END Includes */

TIM_HandleTypeDef htim2;

UART_HandleTypeDef huart1;
UART_HandleTypeDef huart2;

/* USER CODE BEGIN PV */




static char uart_buf[64];
static uint32_t last_measure_tick = 0;







static uint8_t modbus_rx_buf[MODBUS_REQUEST_SIZE];
static uint8_t modbus_tx_buf[MODBUS_MAX_RESPONSE_SIZE];

static volatile uint8_t modbus_request_ready = 0U;

/* USER CODE END PV */

void SystemClock_Config(void);
static void MX_GPIO_Init(void);
static void MX_USART2_UART_Init(void);
static void MX_USART1_UART_Init(void);
static void MX_TIM2_Init(void);
/**
  * @brief  The application entry point.
  * @retval int
  */
int main(void)
{

  /* MCU Configuration--------------------------------------------------------*/

  /* Reset of all peripherals, Initializes the Flash interface and the Systick. */
  HAL_Init();

  /* Configure the system clock */
  SystemClock_Config();

  /* Initialize all configured peripherals */
  MX_GPIO_Init();
  MX_USART2_UART_Init();
  MX_USART1_UART_Init();
  MX_TIM2_Init();
  /* USER CODE BEGIN 2 */




  HCSR04_Init(&htim2);
  AppConfig_Init();
  ParkingLogic_Init();
  RGB_LED_Init();


  HAL_UART_Receive_IT(
      &huart1,
      modbus_rx_buf,
      MODBUS_REQUEST_SIZE
  );

  /* USER CODE END 2 */

  /* Infinite loop */
  /* USER CODE BEGIN WHILE */
  while (1)
  {
	  HCSR04_Task();




	  if (HCSR04_IsDataReady())
	  {
	      uint32_t distance_mm =
	          HCSR04_GetDistanceMm();

	      uint8_t distance_valid =
	          HCSR04_IsDistanceValid();

	      ParkingLogic_Update(
	          distance_mm,
	          distance_valid,
	          HAL_GetTick()
	      );

	      ParkingState_t parking_state =
	          ParkingLogic_GetState();

	      const char *state_str;

	      switch (parking_state)
	      {
	          case PARKING_STATE_FREE:
	              RGB_LED_SetColor(RGB_LED_GREEN);
	              break;

	          case PARKING_STATE_OCCUPIED:
	              RGB_LED_SetColor(RGB_LED_RED);
	              break;

	          case PARKING_STATE_ERROR:
	          default:
	              RGB_LED_SetColor(RGB_LED_BLUE);
	              break;
	      }


	      switch (parking_state)
	      {
	          case PARKING_STATE_FREE:
	              state_str = "FREE";
	              break;

	          case PARKING_STATE_OCCUPIED:
	              state_str = "OCCUPIED";
	              break;

	          case PARKING_STATE_ERROR:
	          default:
	              state_str = "ERROR";
	              break;
	      }

	      int len = snprintf(
	          uart_buf,
	          sizeof(uart_buf),
	          "Dist:%lu mm Valid:%u Parking:%s Err:%u\r\n",
	          (unsigned long)distance_mm,
	          distance_valid,
	          state_str,
	          HCSR04_GetLastError()
	      );

	      HAL_UART_Transmit(
	          &huart2,
	          (uint8_t *)uart_buf,
	          len,
	          100
	      );

	      HCSR04_ClearDataReady();
	  }

	    uint32_t now = HAL_GetTick();

	    if ((now - last_measure_tick) >= 100U)
	    {
	        last_measure_tick = now;
	        HCSR04_StartMeasurement();
	    }






	    if (modbus_request_ready)
	    {
	        uint16_t response_len =
	            ModbusRTU_ProcessRequest(
	                modbus_rx_buf,
	                MODBUS_REQUEST_SIZE,
	                modbus_tx_buf,
	                sizeof(modbus_tx_buf)
	            );

	        if (response_len > 0U)
	        {
	            /* RS485 transmit mode: DE=1, /RE=1 */
	            HAL_GPIO_WritePin(
	                RS485_DE_RE_GPIO_Port,
	                RS485_DE_RE_Pin,
	                GPIO_PIN_SET
	            );

	            HAL_UART_Transmit(
	                &huart1,
	                modbus_tx_buf,
	                response_len,
	                100U
	            );

	            /* RS485 receive mode: DE=0, /RE=0 */
	            HAL_GPIO_WritePin(
	                RS485_DE_RE_GPIO_Port,
	                RS485_DE_RE_Pin,
	                GPIO_PIN_RESET
	            );
	        }

	        modbus_request_ready = 0U;

	        HAL_UART_Receive_IT(
	            &huart1,
	            modbus_rx_buf,
	            MODBUS_REQUEST_SIZE
	        );
	    }
    /* USER CODE END WHILE */

    /* USER CODE BEGIN 3 */
  }
  /* USER CODE END 3 */
}

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
/* USER CODE BEGIN 4 */
void HAL_TIM_IC_CaptureCallback(TIM_HandleTypeDef *htim)
{
	HCSR04_InputCaptureCallback(htim);
}

void HAL_UART_RxCpltCallback(UART_HandleTypeDef *huart)
{
    if (huart == &huart1)
    {
        modbus_request_ready = 1U;
    }
}
/* USER CODE END 4 */
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


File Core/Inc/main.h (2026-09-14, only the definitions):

#define B1_Pin GPIO_PIN_13
#define B1_GPIO_Port GPIOC
#define HCSR04_TRIG_Pin GPIO_PIN_1
#define HCSR04_TRIG_GPIO_Port GPIOA
#define USART_TX_Pin GPIO_PIN_2
#define USART_TX_GPIO_Port GPIOA
#define USART_RX_Pin GPIO_PIN_3
#define USART_RX_GPIO_Port GPIOA
#define LD2_Pin GPIO_PIN_5
#define LD2_GPIO_Port GPIOA
#define RGB_R_Pin GPIO_PIN_12
#define RGB_R_GPIO_Port GPIOB
#define RGB_G_Pin GPIO_PIN_13
#define RGB_G_GPIO_Port GPIOB
#define RGB_B_Pin GPIO_PIN_14
#define RGB_B_GPIO_Port GPIOB
#define TMS_Pin GPIO_PIN_13
#define TMS_GPIO_Port GPIOA
#define TCK_Pin GPIO_PIN_14
#define TCK_GPIO_Port GPIOA
#define SWO_Pin GPIO_PIN_3
#define SWO_GPIO_Port GPIOB
#define RS485_DE_RE_Pin GPIO_PIN_5
#define RS485_DE_RE_GPIO_Port GPIOB

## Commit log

2026-08-03 chore: initialize STM32CubeIDE project structure
2026-08-04 chore: configure initial peripherals and pin map
2026-09-07 docs: update README and prototype pin map
2026-09-07 hardware: add carrier PCB design and 3D renders
    [parking_sensor_node.kicad_pcb, parking_sensor_node.kicad_sch]
2026-09-14 feat: add RS485 DE/RE control for carrier PCB
2026-09-14 hardware: carrier PCB for fabrication
    [parking_sensor_node-B_Cu.gbr, parking_sensor_node-B_Mask.gbr, parking_sensor_node-B_Silkscreen.gbr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]
2026-09-14 docs: update PCB fabrication status
